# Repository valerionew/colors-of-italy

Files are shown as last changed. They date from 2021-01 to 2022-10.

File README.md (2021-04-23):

# Colors of Italy

# <a href="https://valerionew.github.io/colors-of-italy/" target="_blank">https://valerionew.github.io/colors-of-italy/</a>
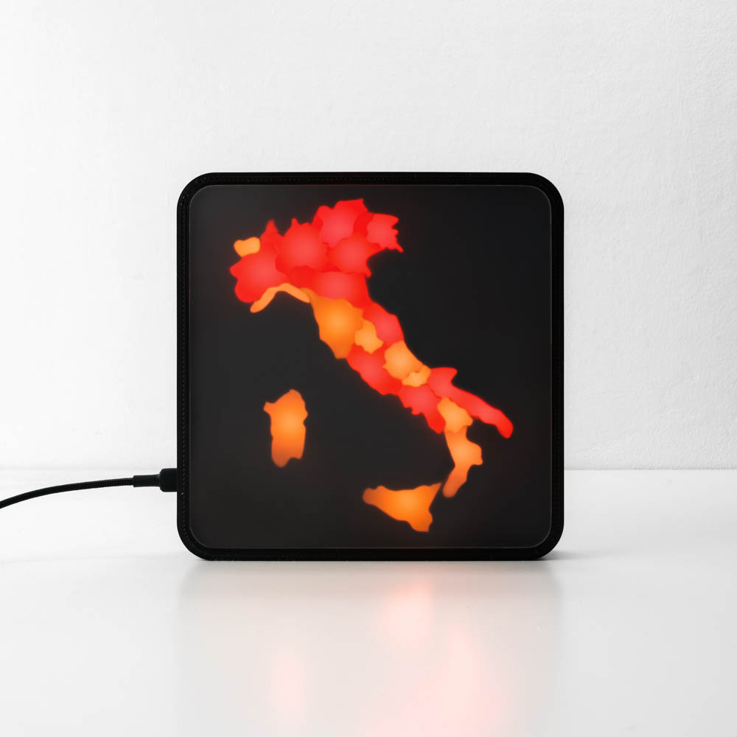
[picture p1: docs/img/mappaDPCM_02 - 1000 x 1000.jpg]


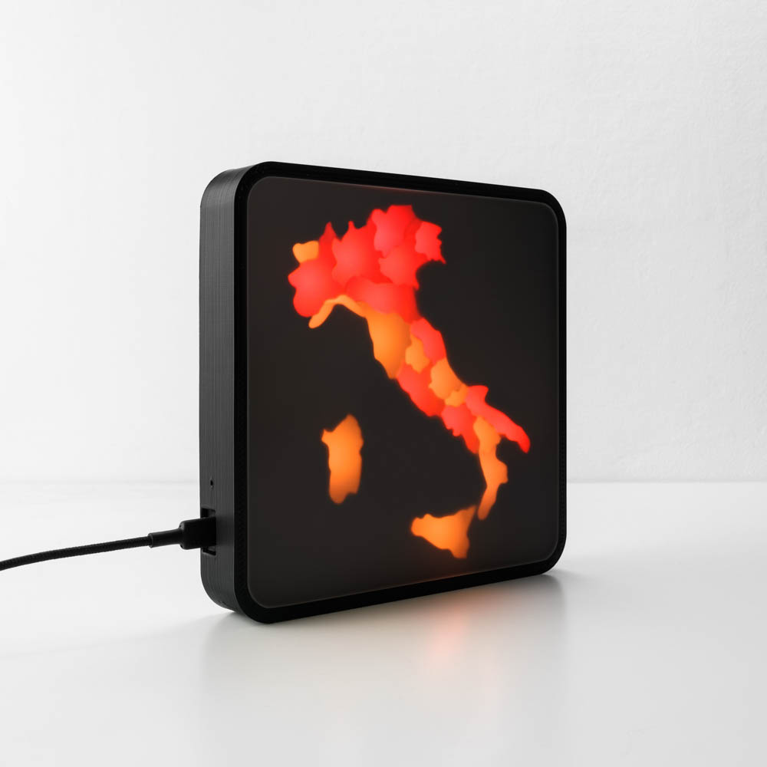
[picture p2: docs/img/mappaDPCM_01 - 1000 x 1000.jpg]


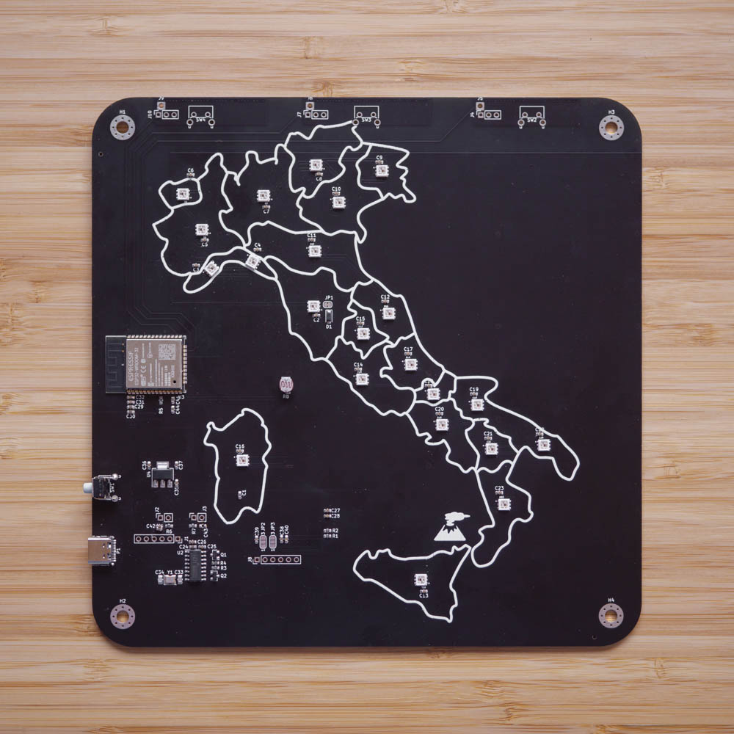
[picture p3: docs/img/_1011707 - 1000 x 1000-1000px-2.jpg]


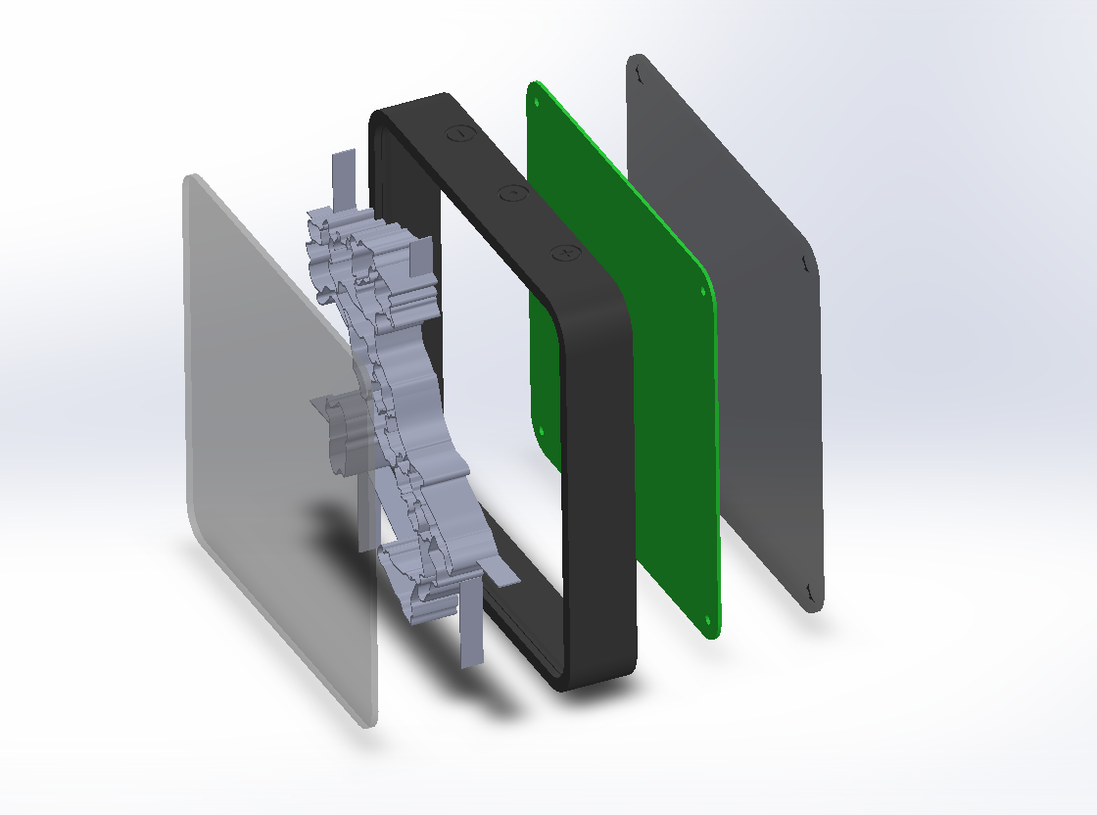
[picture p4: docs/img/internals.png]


inspired by http://www.lucadentella.it/en/2021/01/09/impariamo-insieme-mappa-dinamica-con-arduino/

Using https://github.com/wokwi/kicad-jlcpcb-bom-plugin for BOM management

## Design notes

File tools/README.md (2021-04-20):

## Colors of Italy Tools
Here are some tools for calibration and debug of the system

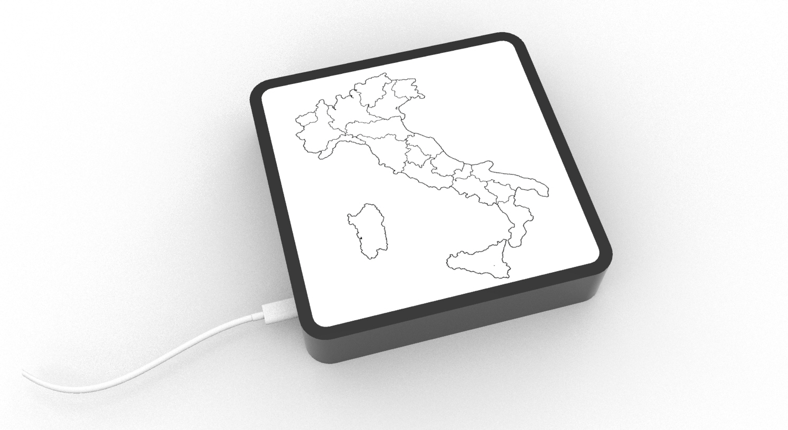
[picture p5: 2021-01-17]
proof-of-concept/proof-of-concept-v.jpg

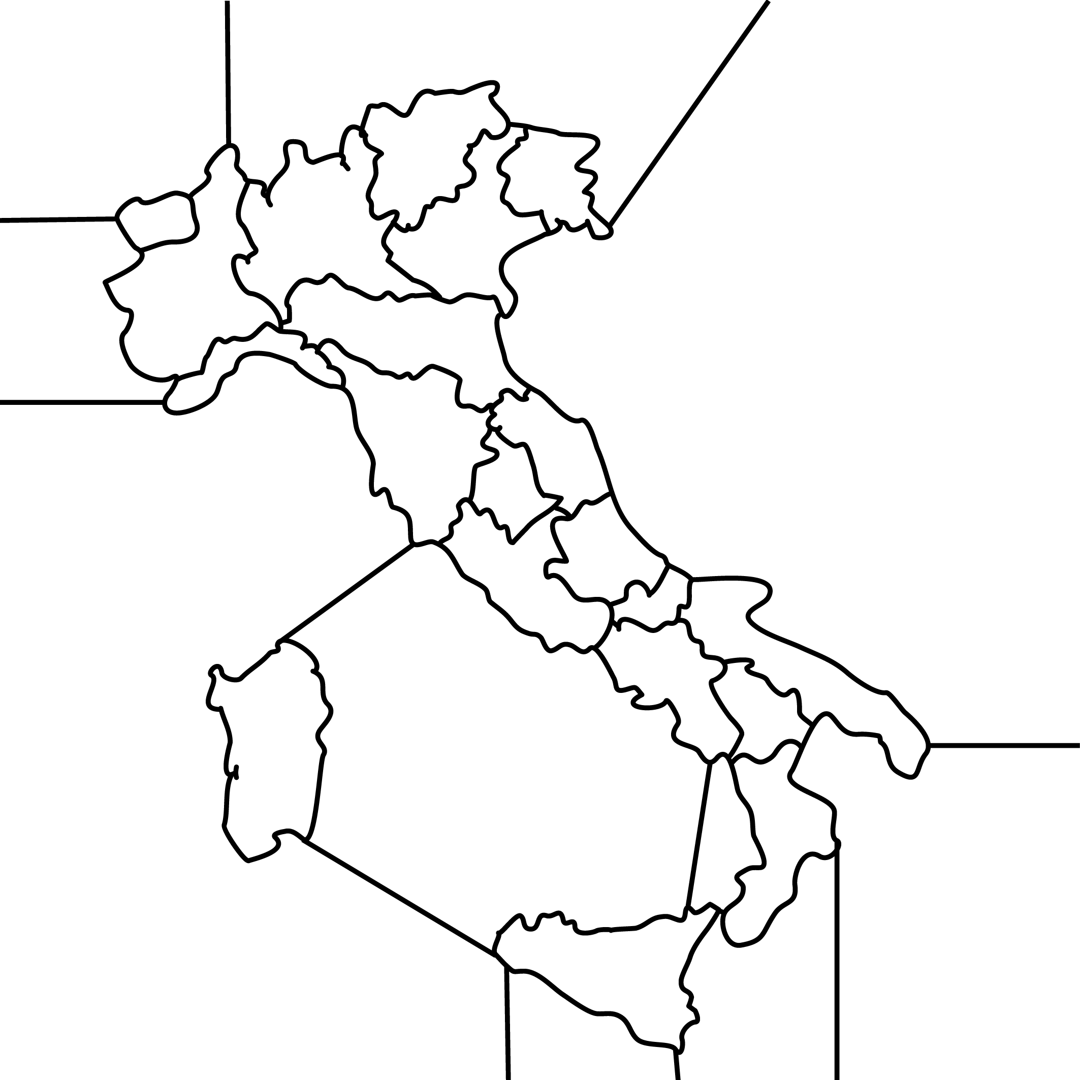
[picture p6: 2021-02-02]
hardware/confini-per-pcb-art-01.png

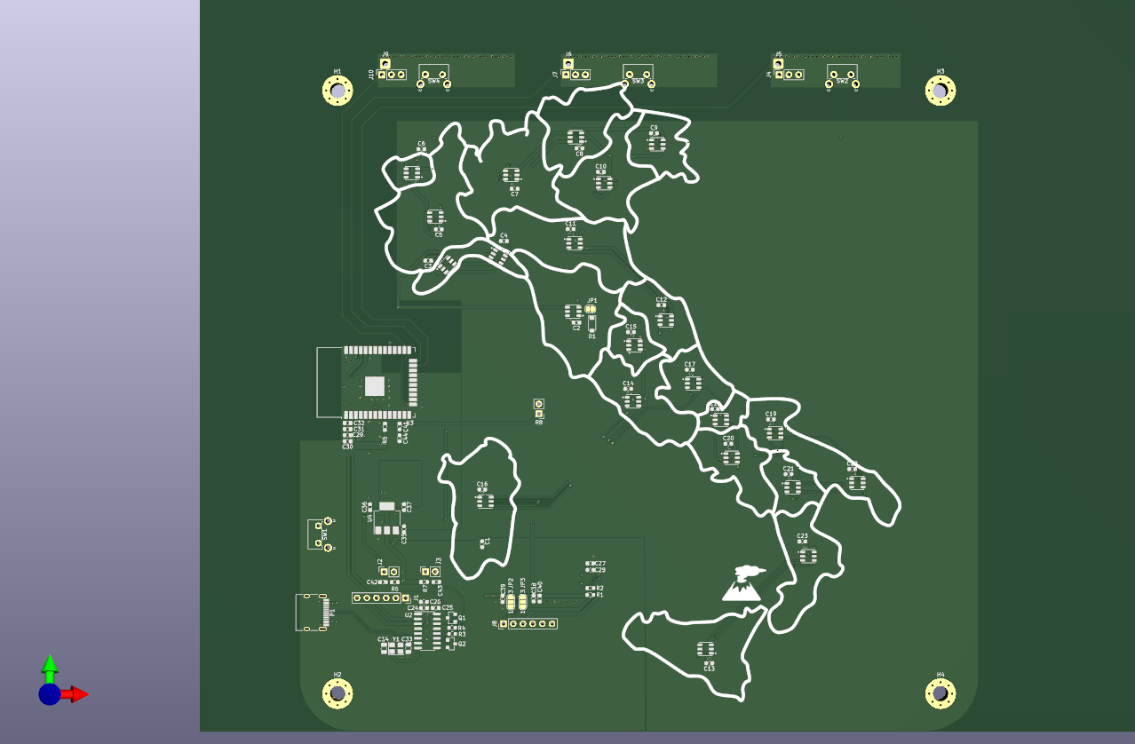
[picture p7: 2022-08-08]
hardware/Colors-of-Italy-pcb.png

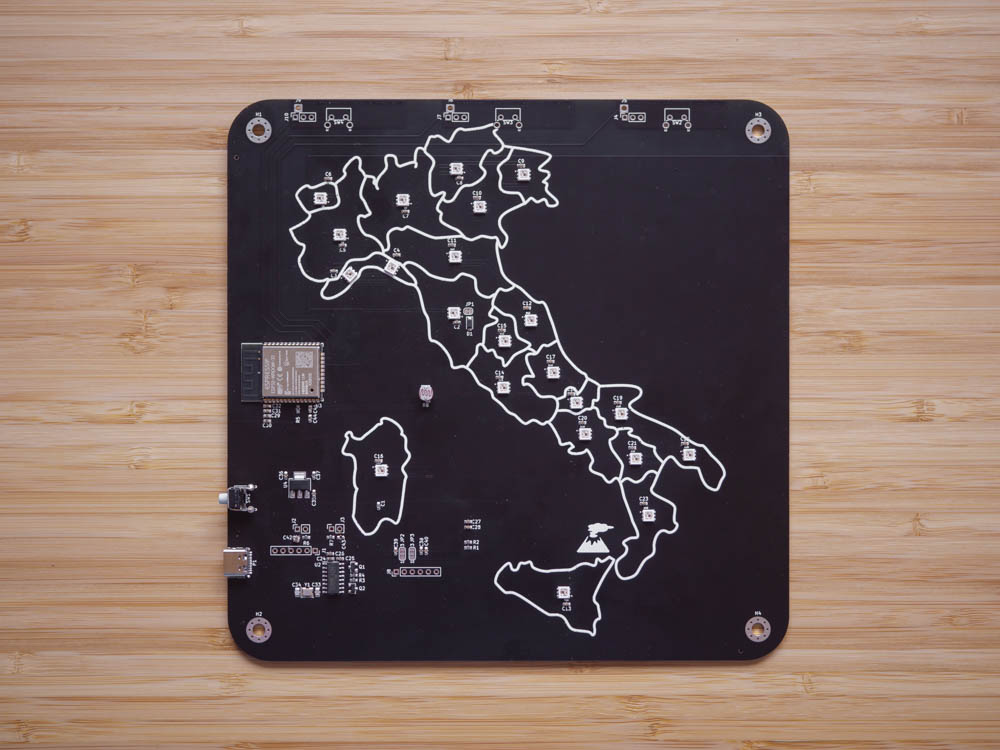
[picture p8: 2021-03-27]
docs/img/_1011707 - 1000 x 1000.jpg

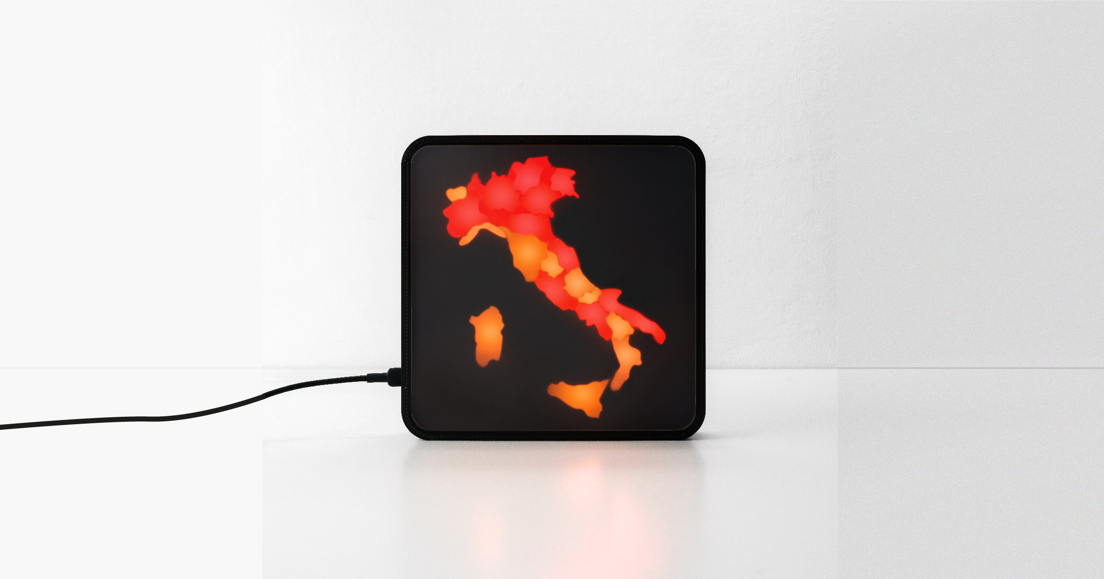
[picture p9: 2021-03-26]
docs/img/mappaDPCM_02 - thumbnail.jpg

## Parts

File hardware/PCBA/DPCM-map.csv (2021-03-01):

Comment | Designator | Footprint | LCSC Part #
10u Unpolarized capacitor | C1,C24,C27,C29,C30,C35,C37,C38,C39,C41,C43,C44 | C_0603_1608Metric | C19702
100n Unpolarized capacitor | C2,C3,C4,C5,C6,C7,C8,C9,C10,C11,C12,C13,C14,C15,C16,C17,C18,C19,C20,C21,C22,C23,C25,C26,C28,C31,C32,C36,C40,C42 | C_0603_1608Metric | C14663
18p Unpolarized capacitor, small symbol | C33,C34 | C_0805_2012Metric | C1797
1N4148W 100V 0.15A standard switching diode, DO-35 | D1 | D_SOD-123 | C81598
WS2813 RGB LED with integrated controller | D2,D3,D4,D5,D6,D7,D8,D9,D10,D11,D12,D13,D14,D15,D16,D17,D18,D19,D20,D21,D22,D23 | LED_WS2813-MINI | C189639
USB_C_Plug USB Type-C Plug connector | P1 | USB_C_Receptacle_HRO_TYPE-C-31-M-12 | C165948
2N7002 N-MOSFET transistor, gate/source/drain | Q1,Q2 | SOT-23 | C8545
10k Resistor | R1,R2,R3,R4,R5,R6,R7 | R_0603_1608Metric | C25804
CH340G USB serial converter, UART, SOIC-16 | U2 | SOIC-16_3.9x9.9mm_P1.27mm | C14267
ESP32-WROOM-32 RF Module, ESP32-D0WDQ6 SoC, Wi-Fi 802.11b/g/n, Bluetooth, BLE, 32-bit, 2.7-3.6V, onboard antenna, SMD | U3 | ESP32-WROOM-32 | C82899
AZ1117-3.3 1A 20V Fixed LDO Linear Regulator, 3.3V, SOT-89/SOT-223/TO-220/TO-252/TO-263 | U4 | SOT-223-3_TabPin2 | C6186
12MHz Four pin crystal, GND on pins 2 and 4 | Y1 | Crystal_SMD_3225-4Pin_3.2x2.5mm | C9002

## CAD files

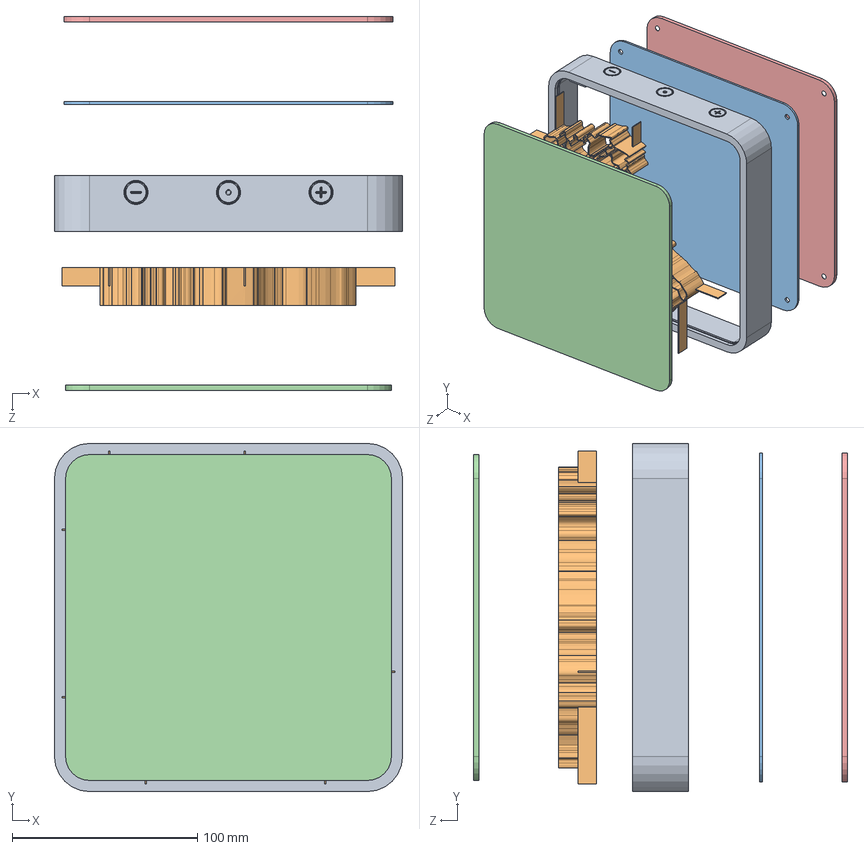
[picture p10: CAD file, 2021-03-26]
mechanical/Assembly-lite.SLDASM
188.1 x 188.1 x 202.0 mm
frame-lite
regioni^Assembly-lite
PCB^Assembly-lite
front^Assembly-lite
back^Assembly-lite

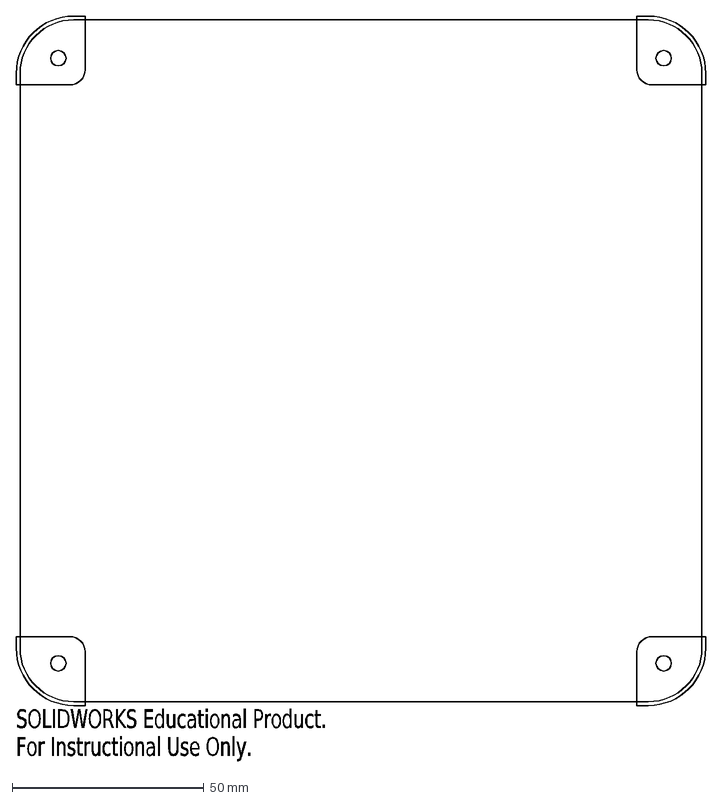
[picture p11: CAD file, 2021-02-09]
hardware/keepouts.dxf
SOLIDWORKS Educational Product.
For Instructional Use Only.

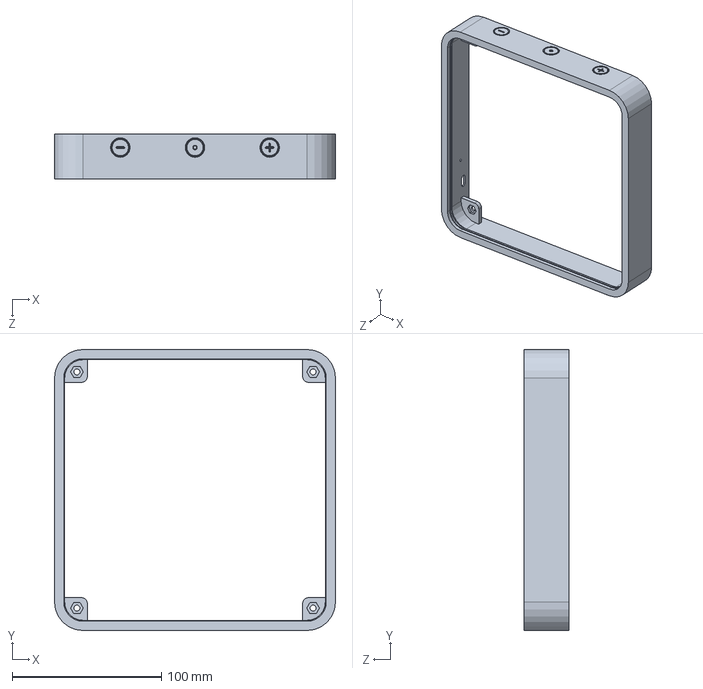
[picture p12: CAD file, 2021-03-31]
mechanical/frame-lite.SLDPRT
188.1 x 188.1 x 30.0 mm

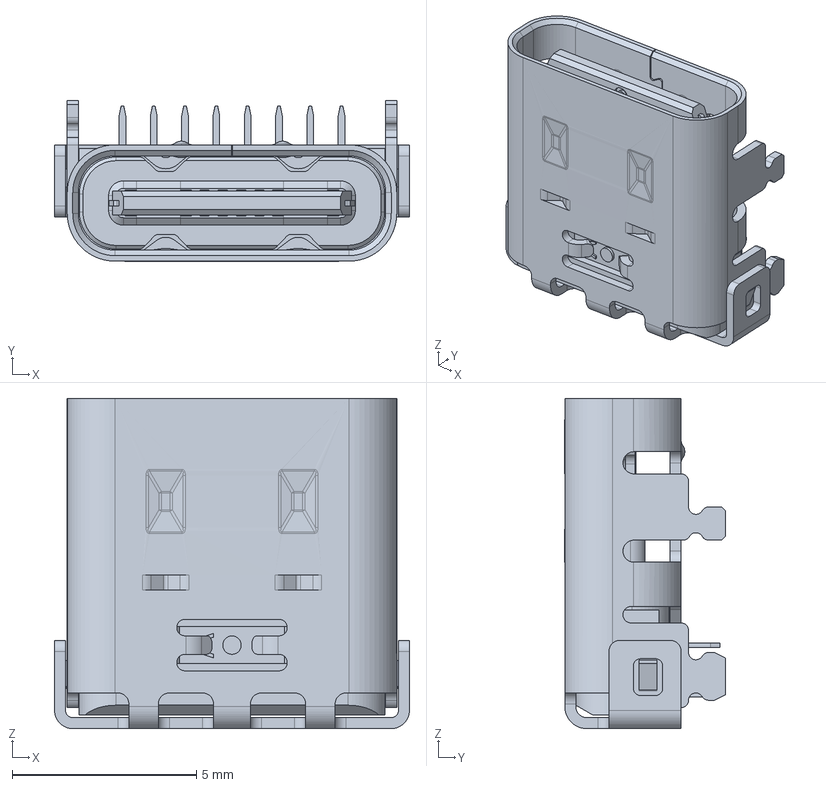
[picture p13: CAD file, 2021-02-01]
mechanical/assets/2137160001.stp
9.64 x 4.36 x 8.97 mm

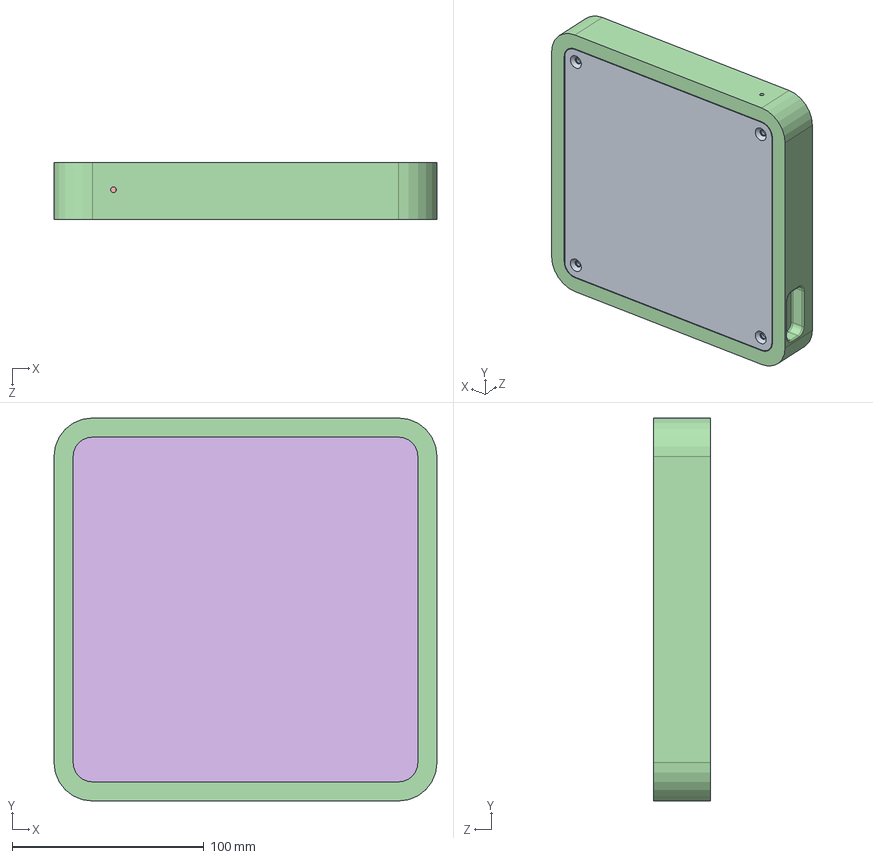
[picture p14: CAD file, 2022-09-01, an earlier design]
mechanical/old/Assembly.SLDASM
200.0 x 200.0 x 30.0 mm
PCB
Part1^Assembly
frame
regioni^Assembly

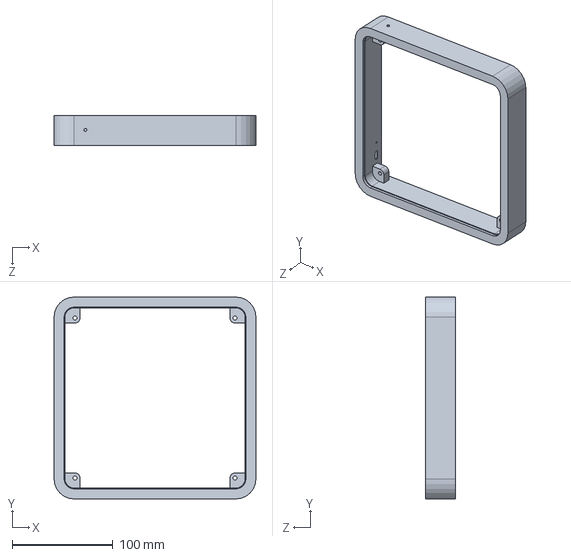
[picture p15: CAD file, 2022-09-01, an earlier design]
mechanical/old/frame.SLDPRT
200.0 x 200.0 x 30.0 mm

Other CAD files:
mechanical/assets/top-buttons.dxf
mechanical/STL/3MF/CE3_frame-lite.3mf
mechanical/STL/back.dxf
hardware/edges.dxf
mechanical/assets/italy-supports.dxf
mechanical/STL/front.dxf
mechanical/assets/italy-support.dxf
mechanical/old/Assembly-lite.SLDASM
mechanical/old/screen.SLDPRT
mechanical/old/Coperchio.SLDPRT
mechanical/old/frame-lite.SLDPRT
mechanical/old/PCB.SLDPRT
mechanical/STL/frame-lite.stl
mechanical/old/regioni.SLDPRT
proof-of-concept/proof-of-concept-v.3dm

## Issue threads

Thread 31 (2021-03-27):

Mappa vaccinati

Testato, 2021-03-27:
Come già fatto sul progetto di Luca dentella usare la mappa anche per visualizzare l'andazzo dei vaccinati.

Un paio di visualizzazioni utili:
- percentuali di vaccini iniettati rispetto ai consegnati per regione
- percentuali di vaccinati rispetto alla popolazione della regione

Closed 2022-07-30.

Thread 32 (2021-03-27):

Pdf pcb+sch

Testato, 2021-03-27:
Per chi al volo, magari su smartphone, vuole dare un'occhiata a schema elettrico e pcb, è utile inserire due .pdf aggiornati di volta in volta all'ultima release

valerionew, 2021-04-10:
Grazie per il suggerimento, fatto in 288a203!

Testato, 2022-08-06:
è stato aggiunto solo il .pdf dello schema, non anche il .pdf del pcb ?

Testato, 2022-08-08:
Closed by https://github.com/valerionew/colors-of-italy/commit/67d5a37c0be215f8fd7a4a17aa0f6b96717bcda0

Closed 2022-08-08.

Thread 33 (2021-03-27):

fetch dei dati

WAPEETY, 2021-03-27:
Salve, per essere sicuri che i dati siano sempre aggiornati non converrebbe prenderli da [https://github.com/pcm-dpc/COVID-19](https://github.com/pcm-dpc/COVID-19) ?

vi ringrazio in anticipo per la risposta.

valerionew, 2021-04-10:
Ciao e grazie per il suggerimento.
Quelli distribuiti dalla protezione civile sono dei [JSON enormi](https://raw.githubusercontent.com/pcm-dpc/COVID-19/master/aree/geojson/dpc-covid-19-ita-aree.json), non è molto conveniente scaricarli e parsarli sul dispositivo. In più avevamo già questi dati per un altro progetto di @lorossi, che fa scraping su una pagina del ministero, quindi sono comunque aggiornati

WAPEETY, 2021-04-10:
In effetti ho notato adesso, scaricarli e parsarli su un ESP sarebbe praticamente una mazzata mazzata per il microcontrollore ahahahah.
Grazie ancora, chiudo la issue

Closed 2021-04-10.

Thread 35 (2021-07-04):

Portscan bug

Testato, 2021-07-04:
lanciando un portscan verso il device, la mappa inizia a lampeggiare.
Alla fine del port scan la mappa puo' risultare a volte accesa ed a volte spenta

valerionew, 2021-07-04:
Confermato

valerionew, 2021-07-04:
Da prime prove sembra dovuto a un'interferenza tra i bottoni touch e l'uso del wifi

Testato, 2021-07-04:
Concordo, è lo stesso effetto di quando ti avvicini colle mani.
Il touch è il tallone d'Achille del progetto

valerionew, 2021-07-04:
Nella roadmap non ci doveva nemmeno essere per la v1, abbiamo deciso di inserirlo nell'hardware "per uso futuro" e abbiamo tentato un'implementazione. È sicuramente una criticità, ma non è mai stato uno dei punti chiave del progetto - tanto che per metà è disabilitato e funziona solo il tasto centrale

Testato, 2021-07-04:
io prenderei in considerazione un update per rimuovere anche il tasto centrale, tanto dà solo problemi e se si vuole spegnere si stacca il cavo

valerionew, 2021-07-04:
Io lo uso ogni sera sulla mia unità, ma effettivamente alcune mattine la trovo accesa. Se vuoi ti mando un compilato senza tasto centrale, se pensi sia più comodo

Testato, 2021-07-04:
non preoccuparti, era giusto per segnalare la issue, se impegno ci deve essere è meglio mettere mano al touch in se

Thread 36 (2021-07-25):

Splashscreen

Testato, 2021-07-25:
aggiungere una qualsiasi animazione, o anche una semplice accensione di tutti i led per 1sec, al boot.
Questo aiuta il debug nel caso in cui, causa rpobemi magari al server, la lampada rimane completamente spenta (come è in questo momento), ed anche staccando e riattaccando l'alimentazione non c'e' segno di vita, facendo erroneamente credere che magari non c'e' alimentazione, o sono rotti i led, ecc ecc

Testato, 2022-10-16:
Inserita bandiera italiana al boot

Closed 2022-10-16.

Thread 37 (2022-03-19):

[Feature Request] Wars of Italy

Testato, 2022-03-19:
Rilasciare un nuovo firmware che permetta la visualizzazione delle regioni bombardate nel caso si arrivi ad una guerra con Putin

Testato, 2022-07-30:
speriamo non serva 😅

Closed 2022-07-30.

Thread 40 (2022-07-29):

Down vaccinocovid19.live

Testato, 2022-07-29:
Risulta down vaccinocovid19.live, sia tentando di raggiungere l'indirizzo via browser sia confermato da debug seriale
Il device resta su schermata nera

```
cer*WM: [3] lastconxresult: WL_CONNECTED                                
[E][WiFiGeneric.cpp:739] hostByName(): DNS Failed for vaccinocovid19.live
[E][WiFiClientSecure.cpp:127] connect(): start_ssl_client: -1           
[E][WiFiGeneric.cpp:739] hostByName(): DNS Failed for vaccinocovid19.live
[E][WiFiClientSecure.cpp:127] connect(): start_ssl_client: -1
```

valerionew, 2022-07-30:
@lorossi

Testato, 2022-10-16:
Rimossa la necessità di un server esterno

Closed 2022-10-16.

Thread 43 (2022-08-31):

Reverse USB-C

Testato, 2022-08-31:
L'attuale modello di connettore Usb-C fa perdere la funzionalità di reverse del cavo Usb-c.
Cambiare modello in caso di nuova produzione

valerionew, 2022-08-31:
Pro USB c full:
- Funziona con tutti i cavi in tutti gli orientamenti
Contro USB c full:
- Non testato
- Considerevolmente più costoso
- Non se ne accorge praticamente nessuno, se non durante lo sviluppo

Testato, 2022-08-31:
Non testato in che senso ? Funziona al 100% il reverse sul connettore giusto.
Per il prezzo bisogna vedere, magari costa 2€ invece di 1€
il terzo punto è incontestabile :-)

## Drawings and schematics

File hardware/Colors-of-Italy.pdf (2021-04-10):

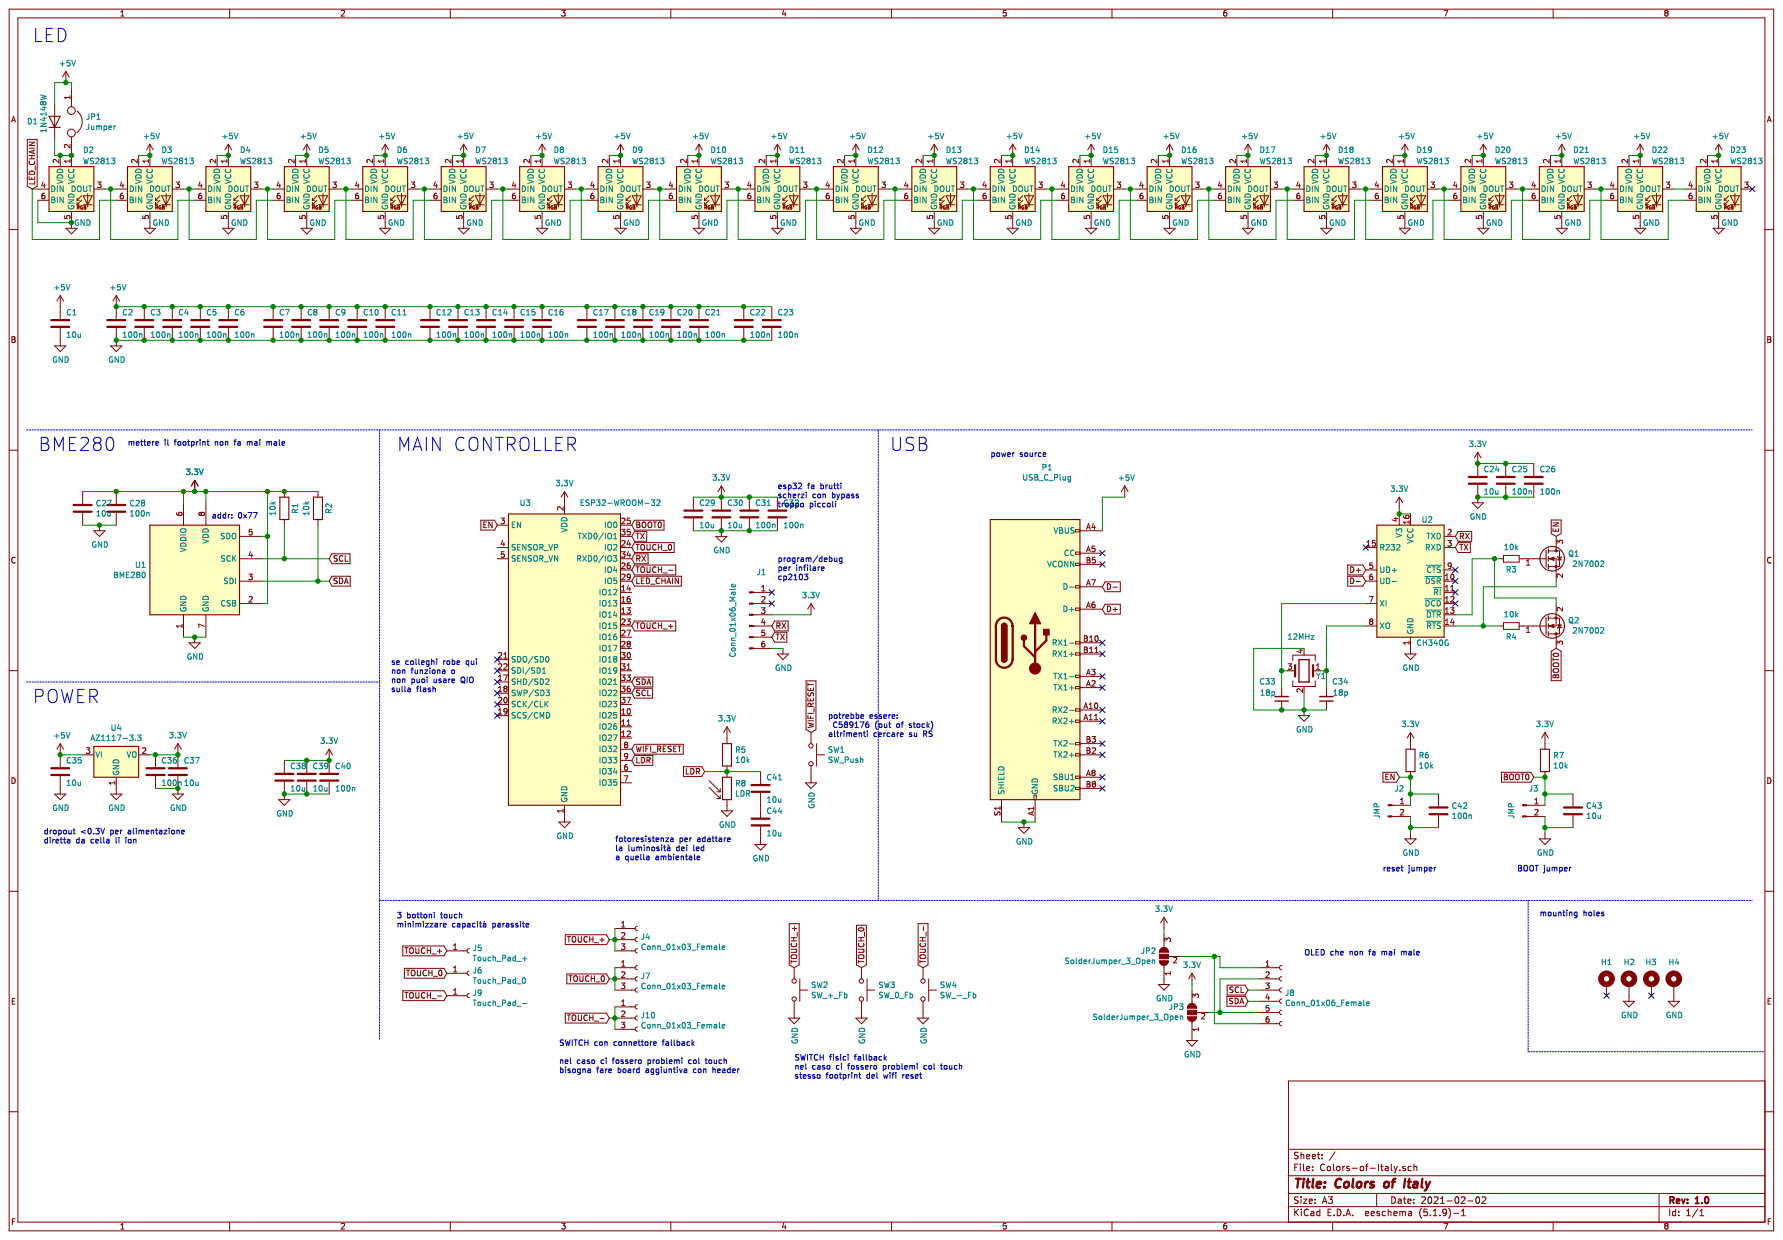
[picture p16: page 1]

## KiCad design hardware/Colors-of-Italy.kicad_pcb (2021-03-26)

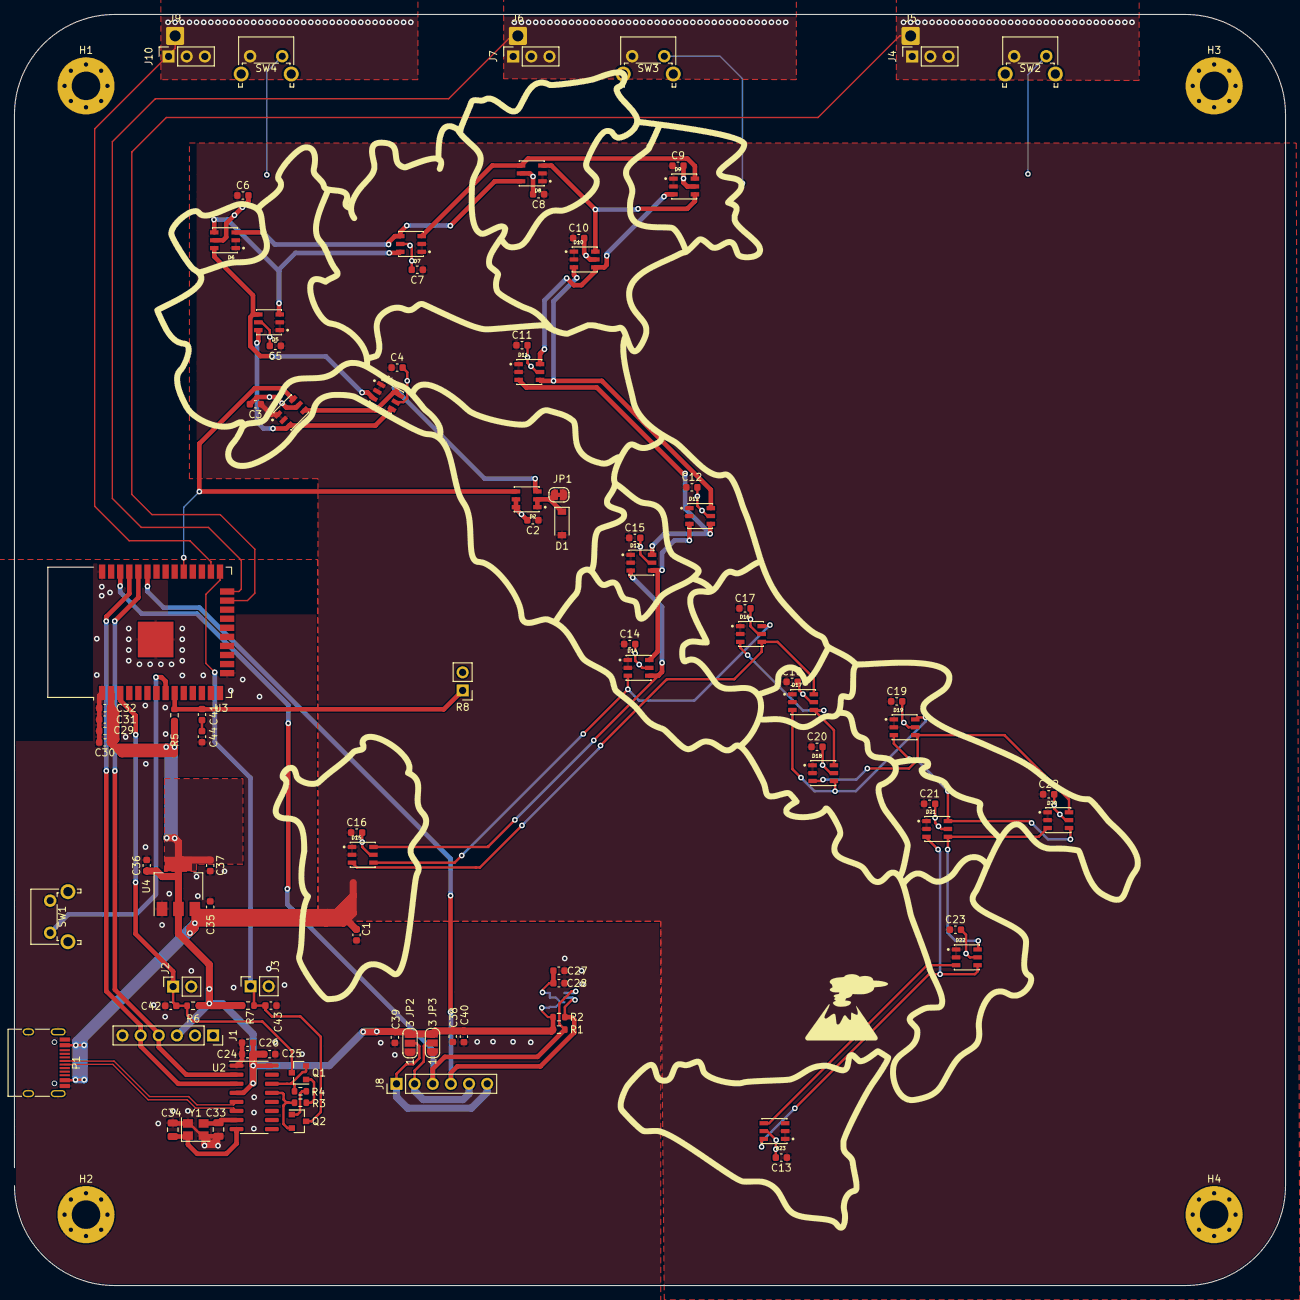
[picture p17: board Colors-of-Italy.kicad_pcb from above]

Board: 2 copper layers, 178.0 x 178.0 mm, 104 parts (1 on the bottom side), 48 nets.

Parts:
C1, C24, C27, C29, C30, C35, C37, C38, C39, C41, C43, C44: 10u; C_0603_1608Metric
C2, C3, C4, C5, C6, C7, C8, C9, C10, C11, C12, C13, C14, C15, C16, C17, C18, C19, C20, C21, C22, C23, C25, C26, C28, C31, C32, C36, C40, C42: 100n; C_0603_1608Metric
C33, C34: 18p; C_0805_2012Metric
D1: 1N4148W; D_SOD-123
D2, D3, D4, D5, D6, D7, D8, D9, D10, D11, D12, D13, D14, D15, D16, D17, D18, D19, D20, D21, D22, D23: WS2813; LED_WS2813-MINI
H1, H2, H3, H4: MountingHole_Pad; MountingHole_4mm_Pad_Via
J1: Conn_01x06_Male; PinSocket_1x06_P2.54mm_Vertical
J2, J3: JMP; PinSocket_1x02_P2.54mm_Vertical
J4, J7, J10: Conn_01x03_Female; PinSocket_1x03_P2.54mm_Vertical
J5: Touch_Pad_+; SolderWire-0.75sqmm_1x01_D1.25mm_OD2.3mm
J6: Touch_Pad_0; SolderWire-0.75sqmm_1x01_D1.25mm_OD2.3mm
J8: Conn_01x06_Female; PinHeader_1x06_P2.54mm_Vertical
J9: Touch_Pad_-; SolderWire-0.75sqmm_1x01_D1.25mm_OD2.3mm
JP1: Jumper; SolderJumper-2_P1.3mm_Bridged_RoundedPad1.0x1.5mm
JP2, JP3: SolderJumper_3_Open; SolderJumper-3_P1.3mm_Open_RoundedPad1.0x1.5mm_NumberLabels
P1: USB_C_Plug; USB_C_Receptacle_HRO_TYPE-C-31-M-12
Q1, Q2: 2N7002; SOT-23
R1, R2, R3, R4, R5, R6, R7: 10k; R_0603_1608Metric
R8: LDR; PinHeader_1x02_P2.54mm_Vertical
SW1: SW_Push; SW_Tactile_SPST_Angled_PTS645Vx58-2LFS
SW2: SW_+_Fb; SW_Tactile_SPST_Angled_PTS645Vx58-2LFS
SW3: SW_0_Fb; SW_Tactile_SPST_Angled_PTS645Vx58-2LFS
SW4: SW_-_Fb; SW_Tactile_SPST_Angled_PTS645Vx58-2LFS
U1: BME280; Bosch_LGA-8_2.5x2.5mm_P0.65mm_ClockwisePinNumbering
U2: CH340G; SOIC-16_3.9x9.9mm_P1.27mm
U3: ESP32-WROOM-32
U4: AZ1117-3.3; SOT-223-3_TabPin2
Y1: 12MHz; Crystal_SMD_3225-4Pin_3.2x2.5mm

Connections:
+3V3: C24.1, C25.1, C26.1, C27.1, C28.1, C29.1, C30.1, C31.1, C32.1, C36.1, C37.1, C38.1, C39.1, C40.1, J1.3, JP2.3, JP3.3, R1.2, R2.2, R5.1, R6.1, R7.1, U1.2, U1.5, U1.6, U1.8, U2.4, U2.16, U3.2, U4.2
+5V: C1.1, C2.1, C3.1, C4.1, C5.1, C6.1, C7.1, C8.1, C9.1, C10.1, C11.1, C12.1, C13.1, C14.1, C15.1, C16.1, C17.1, C18.1, C19.1, C20.1, C21.1, C22.1, C23.1, C35.1, D1.2, D3.1, D3.2, D4.1, D4.2, D5.1, D5.2, D6.1, D6.2, D7.1, D7.2, D8.1, D8.2, D9.1, D9.2, D10.1, D10.2, D11.1, D11.2, D12.1, D12.2, D13.1, D13.2, D14.1, D14.2, D15.1, D15.2, D16.1, D16.2, D17.1, D17.2, D18.1, D18.2, D19.1, D19.2, D20.1, D20.2, D21.1, D21.2, D22.1, D22.2, D23.1, D23.2, JP1.1, P1.A4, P1.A9, P1.B4, P1.B9, U4.3
BOOT0: C43.1, J3.1, Q2.3, R7.2, U3.25
D+: P1.A6, U2.5
D-: P1.A7, U2.6
EN: C42.1, J2.1, Q1.3, R6.2, U3.3
GND: C1.2, C2.2, C3.2, C4.2, C5.2, C6.2, C7.2, C8.2, C9.2, C10.2, C11.2, C12.2, C13.2, C14.2, C15.2, C16.2, C17.2, C18.2, C19.2, C20.2, C21.2, C22.2, C23.2, C24.2, C25.2, C26.2, C27.2, C28.2, C29.2, C30.2, C31.2, C32.2, C33.1, C34.1, C35.2, C36.2, C37.2, C38.2, C39.2, C40.2, C42.2, C43.2, C44.2, D2.5, D2.6, D3.5, D4.5, D5.5, D6.5, D7.5, D8.5, D9.5, D10.5, D11.5, D12.5, D13.5, D14.5, D15.5, D16.5, D17.5, D18.5, D19.5, D20.5, D21.5, D22.5, D23.5, H2.1, H4.1, J1.6, J2.2, J3.2, JP2.1, JP3.1, P1.A1, P1.A12, P1.B1, P1.B12, P1.S1, R8.2, SW1.2, SW2.2, SW3.2, SW4.2, U1.1, U1.7, U2.1, U3.1, U3.15, U3.38, U3.39, U4.1, Y1.2, Y1.4
LDR: C41.1, R5.2, R8.1, U3.9
LED_CHAIN: D2.4, D3.6, U3.29
unnamed: C33.2, U2.7, Y1.3
unnamed: C34.2, U2.8, Y1.1
unnamed: C41.2, C44.1
unnamed: D1.1, D2.1, D2.2, JP1.2
unnamed: D2.3, D3.4, D4.6
unnamed: D3.3, D4.4, D5.6
unnamed: D4.3, D5.4, D6.6
unnamed: D5.3, D6.4, D7.6
unnamed: D6.3, D7.4, D8.6
unnamed: D7.3, D8.4, D9.6
unnamed: D10.3, D11.4, D12.6
unnamed: D9.3, D10.4, D11.6
unnamed: D8.3, D9.4, D10.6
unnamed: D11.3, D12.4, D13.6
unnamed: D12.3, D13.4, D14.6
unnamed: D13.3, D14.4, D15.6
unnamed: D14.3, D15.4, D16.6
unnamed: D15.3, D16.4, D17.6
unnamed: D16.3, D17.4, D18.6
unnamed: D17.3, D18.4, D19.6
unnamed: D18.3, D19.4, D20.6
unnamed: D19.3, D20.4, D21.6
unnamed: D20.3, D21.4, D22.6
unnamed: D21.3, D22.4, D23.6
unnamed: D22.3, D23.4
unnamed: J8.1, J8.6, JP2.2
unnamed: J8.2, J8.5, JP3.2
unnamed: Q1.1, R3.2
unnamed: Q1.2, R4.1, U2.14
unnamed: Q2.1, R4.2
unnamed: Q2.2, R3.1, U2.13
RX: J1.4, U2.2, U3.34
SCL: J8.3, R1.1, U1.4, U3.36
SDA: J8.4, R2.1, U1.3, U3.33
TOUCH_0: J6.1, J7.1, J7.2, J7.3, SW3.1, U3.24
TOUCH_+: J4.1, J4.2, J4.3, J5.1, SW2.1, U3.23
TOUCH_-: J9.1, J10.1, J10.2, J10.3, SW4.1, U3.26
TX: J1.5, U2.3, U3.35
WIFI_RESET: SW1.1, U3.8

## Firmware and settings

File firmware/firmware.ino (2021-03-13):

#include <WiFi.h>
#include <WebServer.h>
#include <WiFiManager.h> // https://github.com/tzapu/WiFiManager -use development branch to get it working on esp32
#include <ArduinoJson.h> // https://github.com/bblanchon/ArduinoJson
#include <FastLED.h>     // https://github.com/FastLED/FastLED
#include <HTTPClient.h>  // built in library
#include <map>           // built in library
#include <array>         // built in library

#define DEBUG

#define LED_NUMBER 22         // change this with the actual number of leds
#define MAX_LEDS_PER_REGION 2 // change this with the maximum number of led in each region
#define WIFI_TIMEOUT 500
#define WIFI_SSID_NAME "DCPM-map"
#define UPDATE_INTERVAL 10000
#define TERRITORIES_REQUEST_URL "https://vaccinocovid19.live/get/colore_territori_slim"
#define COLORS_REQUEST_URL "https://vaccinocovid19.live/get/colore_territori_rgb"
#define WIFI_RESET_BUTTON 32
#define WIFI_RESET_TIMEOUT 5000
#define WIFI_MAX_TIME 600000
#define LED_PIN 5           // pin connected to WS2812b data cable
#define LIGHT_SENSOR_PIN 33 // must be and ADC PIN, cannot use ADC2
#define NO_LED 255

#define TOUCH_PLUS_PIN T3  // GPIO 4
#define TOUCH_RESET_PIN T2 // GPIO 2
#define TOUCH_MINUS_PIN T0 // GPIO 15

WiFiManager wifiManager;
WiFiClient client;
CRGB leds[LED_NUMBER];

unsigned long last_update;
unsigned long last_pressed;

boolean wifi_connected;

// color mapping
// e.g. red -> color 0 -> 0xdd222a (red)
// initialization
std::map<String, unsigned long> color_map;

// territory mapping
// ISTAT CODE -> led position translation
// e.g. code 01 -> addresses of led_map["01"]
// source https://www.agenziaentrate.gov.it/portale/Strumenti/Codici+attivita+e+tributo/F24+Codici+tributo+per+i+versamenti/Tabelle+dei+codici+tributo+e+altri+codici+per+il+mo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
std::map<String, std::array<byte, MAX_LEDS_PER_REGION>>
    led_map = {
        {"01", {14, NO_LED}}, // ABRUZZO
        {"02", {19, NO_LED}}, // BASILICATA
        {"03", {NO_LED}},     // BOLZANO
        {"04", {20, NO_LED}}, // CALABRIA
        {"05", {16, NO_LED}}, // CAMPANIA
        {"06", {9, NO_LED}},  // EMILIA ROMAGNA
        {"07", {7, NO_LED}},  // FRIULI VENEZIA GIULIA
        {"08", {12, NO_LED}}, // LAZIO
        {"09", {1, 2}},       // LIGURIA
        {"10", {5, NO_LED}},  // LOMBARDIA
        {"11", {10, NO_LED}}, // MARCHE
        {"12", {15, NO_LED}}, // MOLISE
        {"13", {3, NO_LED}},  // PIEMONTE
        {"14", {17, 18}},     // PUGLIA
        {"15", {13, NO_LED}}, // SARDEGNA
        {"16", {21, NO_LED}}, // SICILIA
        {"17", {0, NO_LED}},  // TOSCANA
        {"18", {6, NO_LED}},  // TRENTO
        {"19", {11, NO_LED}}, // UMBRIA
        {"20", {4, NO_LED}},  // VALLE D'AOSTA
        {"21", {8, NO_LED}}   // VENETO
};

// this function gets called when the parameters are set
void wifiParametersSet()
{
#ifdef DEBUG
  Serial.println("Wifi parameters set. Resetting ESP32.");
#endif
  ESP.restart();
}

void setup()
{

#ifdef DEBUG
  Serial.begin(115200);
#endif

  // PINs initialization
  pinMode(WIFI_RESET_BUTTON, INPUT_PULLUP);
  pinMode(LIGHT_SENSOR_PIN, INPUT);

  // variables initialization
  last_update = 0;
  last_pressed = 0;

#ifdef DEBUG
  Serial.println(WiFi.status());
  //wifiManager.resetSettings();
#endif

  // set up WS2812b - in realtà sono 2813 mini
  FastLED.addLeds<WS2812, LED_PIN, GRB>(leds, LED_NUMBER);

  // setup non blocking loop

  wifiManager.setHostname(WIFI_SSID_NAME);
  wifiManager.setConfigPortalBlocking(false);
  wifiManager.setSaveConfigCallback(wifiParametersSet);

  unsigned long wifiStarted = millis();
  if (!wifiManager.autoConnect(WIFI_SSID_NAME))
  {
    while (!wifi_connected)
    {
      // ConfigPortal is now running
      wifiManager.process();

      // handle led animation
      EVERY_N_MILLISECONDS(20)
      {
        pacifica_loop();
        FastLED.show();
      }

      // handle wifi reset button
      if (digitalRead(WIFI_RESET_BUTTON) == LOW)
      {
        if (last_pressed == 0)
        {
          last_pressed = millis();
        }
        else if (millis() - last_pressed > WIFI_RESET_TIMEOUT)
        {
          // delete wifi credentials and reset esp
          wifiManager.resetSettings();
          ESP.restart();
        }
      }
      else if (digitalRead(WIFI_RESET_BUTTON) == HIGH && last_pressed != 0)
      {
        // reset last pressed
        last_pressed = 0;
      }

      // handle wifi timeout
      if (millis() - wifiStarted > WIFI_MAX_TIME)
      {
        // it's taking too long to connect in
        // reset everything
        ESP.restart();
      }
    }
  }
}

void loop()
{
  // check if it's time to update
  if (last_update == 0 || millis() - last_update > UPDATE_INTERVAL)
  {
    // check if client is still connected
    // if not, set the esp in wifimanager again
    if (!client.connected())
    {
      if (!wifiManager.autoConnect(WIFI_SSID_NAME))
      {
        // blocking loop waiting for connection
        // this code gets called after timeout is hit
        ESP.restart();
      }
    }
    last_update = millis();

    HTTPClient http;
    int httpResponseCode;

    // get rgb colors
    http.begin(COLORS_REQUEST_URL);
    httpResponseCode = http.GET();
    if (httpResponseCode > 0)
    {
      StaticJsonDocument<128> doc;
      // buffer size calculated here: https://arduinojson.org/v6/assistant/
      String json_data = http.getString();
      // parse JSON data
      DeserializationError err = deserializeJson(doc, json_data);

      if (!err)
      {
        // no error in parsing
        JsonObject obj = doc.as<JsonObject>();
        for (JsonPair p : obj)
        {
          // iterate through each key and value
          // load color code
          String color_code = p.key().c_str();
          // load color value
          unsigned long color_hex = p.value().as<unsigned long>();
          // assing to map
          color_map[color_code] = color_hex;
#ifdef DEBUG
          Serial.print("color code ");
          Serial.print(color_code);
          Serial.print(" color hex ");
          Serial.println(color_hex);
#endif
        }
      }
    }

    // get territories color
    http.begin(TERRITORIES_REQUEST_URL);
    httpResponseCode = http.GET();
    if (httpResponseCode > 0)
    {
      StaticJsonDocument<512> doc;
      // buffer size calculated here: https://arduinojson.org/v6/assistant/
      String json_data = http.getString();
      // parse JSON data
      DeserializationError err = deserializeJson(doc, json_data);

      if (!err)
      {
        // no error in parsing
        JsonObject obj = doc.as<JsonObject>();
        for (JsonPair p : obj)
        {
          // iterate through each key and value
          // load color code
          String color_code = p.value().as<String>();
          // translate it to actual hex color
          unsigned long color = color_map.find(color_code)->second;
          // load the list of addresses from the map
          std::array<byte, MAX_LEDS_PER_REGION> addresses = led_map.find(p.key().c_str())->second;
          for (const auto &address : addresses)
          {
            // color the corrisponding led
            if (address != NO_LED)
            {
              // the address must be different from the array filler
              leds[address] = color;
            }
          }

#ifdef DEBUG
          Serial.print("key ");
          Serial.print(p.key().c_str());
          Serial.print(" value ");
          Serial.print(p.value().as<byte>());
          Serial.print(" led addresses ");
          for (const auto &address : addresses)
          {
            Serial.print(address);
            Serial.print(" ");
          }
          Serial.print("color code ");
          Serial.print(color_code);
          Serial.print(" color hex ");
          Serial.println(color);
#endif
        }
      }

      // free the memory
      doc.clear();
    }
    http.end();
  }
  // read light level from sensor
  unsigned int light = analogRead(LIGHT_SENSOR_PIN);
  // 500 should be the max value
  // this will need some tweaking
  if (light > 500)
    light = 500;
  // calculate the actual brightness compared to the sensor output
  byte brightness = map(light, 500, 0, 255, 20);
  // set the leds brightness
  FastLED.setBrightness(brightness);

  //      #ifdef DEBUG
  //        Serial.print("ambient light ");
  //        Serial.print(light);
  //        Serial.print(" led brightness ");
  //        Serial.println(brightness);
  //      #endif

  if (digitalRead(WIFI_RESET_BUTTON) == LOW)
  {
    if (last_pressed == 0)
    {
      last_pressed = millis();
    }
    else if (millis() - last_pressed > WIFI_RESET_TIMEOUT)
    {
      // delete wifi credentials and reset esp
      wifiManager.resetSettings();
      ESP.restart();
    }
  }
  else if (digitalRead(WIFI_RESET_BUTTON) == HIGH && last_pressed != 0)
  {
    // reset last pressed
    last_pressed = 0;
  }

  FastLED.show();
  delay(10);
}

//
//  "Pacifica"
//  Gentle, blue-green ocean waves.
//  December 2019, Mark Kriegsman and Mary Corey March.
//  For Dan.
//
CRGBPalette16 pacifica_palette_1 =
    {0x000507, 0x000409, 0x00030B, 0x00030D, 0x000210, 0x000212, 0x000114, 0x000117,
     0x000019, 0x00001C, 0x000026, 0x000031, 0x00003B, 0x000046, 0x14554B, 0x28AA50};
CRGBPalette16 pacifica_palette_2 =
    {0x000507, 0x000409, 0x00030B, 0x00030D, 0x000210, 0x000212, 0x000114, 0x000117,
     0x000019, 0x00001C, 0x000026, 0x000031, 0x00003B, 0x000046, 0x0C5F52, 0x19BE5F};
CRGBPalette16 pacifica_palette_3 =
    {0x000208, 0x00030E, 0x000514, 0x00061A, 0x000820, 0x000927, 0x000B2D, 0x000C33,
     0x000E39, 0x001040, 0x001450, 0x001860, 0x001C70, 0x002080, 0x1040BF, 0x2060FF};

void pacifica_loop()
{
  // Increment the four "color index start" counters, one for each wave layer.
  // Each is incremented at a different speed, and the speeds vary over time.
  static uint16_t sCIStart1, sCIStart2, sCIStart3, sCIStart4;
  static uint32_t sLastms = 0;
  uint32_t ms = GET_MILLIS();
  uint32_t deltams = ms - sLastms;
  sLastms = ms;
  uint16_t speedfactor1 = beatsin16(3, 179, 269);
  uint16_t speedfactor2 = beatsin16(4, 179, 269);
  uint32_t deltams1 = (deltams * speedfactor1) / 256;
  uint32_t deltams2 = (deltams * speedfactor2) / 256;
  uint32_t deltams21 = (deltams1 + deltams2) / 2;
  sCIStart1 += (deltams1 * beatsin88(1011, 10, 13));
  sCIStart2 -= (deltams21 * beatsin88(777, 8, 11));
  sCIStart3 -= (deltams1 * beatsin88(501, 5, 7));
  sCIStart4 -= (deltams2 * beatsin88(257, 4, 6));

  // Clear out the LED array to a dim background blue-green
  fill_solid(leds, LED_NUMBER, CRGB(2, 6, 10));

  // Render each of four layers, with different scales and speeds, that vary over time
  pacifica_one_layer(pacifica_palette_1, sCIStart1, beatsin16(3, 11 * 256, 14 * 256), beatsin8(10, 70, 130), 0 - beat16(301));
  pacifica_one_layer(pacifica_palette_2, sCIStart2, beatsin16(4, 6 * 256, 9 * 256), beatsin8(17, 40, 80), beat16(401));
  pacifica_one_layer(pacifica_palette_3, sCIStart3, 6 * 256, beatsin8(9, 10, 38), 0 - beat16(503));
  pacifica_one_layer(pacifica_palette_3, sCIStart4, 5 * 256, beatsin8(8, 10, 28), beat16(601));

  // Add brighter 'whitecaps' where the waves lines up more
  pacifica_add_whitecaps();

  // Deepen the blues and greens a bit
  pacifica_deepen_colors();
}

// Add one layer of waves into the led array
void pacifica_one_layer(CRGBPalette16 &p, uint16_t cistart, uint16_t wavescale, uint8_t bri, uint16_t ioff)
{
  uint16_t ci = cistart;
  uint16_t waveangle = ioff;
  uint16_t wavescale_half = (wavescale / 2) + 20;
  for (uint16_t i = 0; i < LED_NUMBER; i++)
  {
    waveangle += 250;
    uint16_t s16 = sin16(waveangle) + 32768;
    uint16_t cs = scale16(s16, wavescale_half) + wavescale_half;
    ci += cs;
    uint16_t sindex16 = sin16(ci) + 32768;
    uint8_t sindex8 = scale16(sindex16, 240);
    CRGB c = ColorFromPalette(p, sindex8, bri, LINEARBLEND);
    leds[i] += c;
  }
}

// Add extra 'white' to areas where the four layers of light have lined up brightly
void pacifica_add_whitecaps()
{
  uint8_t basethreshold = beatsin8(9, 55, 65);
  uint8_t wave = beat8(7);

  for (uint16_t i = 0; i < LED_NUMBER; i++)
  {
    uint8_t threshold = scale8(sin8(wave), 20) + basethreshold;
    wave += 7;
    uint8_t l = leds[i].getAverageLight();
    if (l > threshold)
    {
      uint8_t overage = l - threshold;
      uint8_t overage2 = qadd8(overage, overage);
      leds[i] += CRGB(overage, overage2, qadd8(overage2, overage2));
    }
  }
}

// Deepen the blues and greens
void pacifica_deepen_colors()
{
  for (uint16_t i = 0; i < LED_NUMBER; i++)
  {
    leds[i].blue = scale8(leds[i].blue, 145);
    leds[i].green = scale8(leds[i].green, 200);
    leds[i] |= CRGB(2, 5, 7);
  }
}

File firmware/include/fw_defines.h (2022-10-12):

#ifndef FW_DEFINES_H
#define FW_DEFINES_H

//Colori ufficiali Bandiera Italiana
const CRGB VERDE {0x008c45};    //Verde: pantone 17-6153
const CRGB BIANCO {0xf4f5f0};   //Bianco: pantone 11-0601
const CRGB ROSSO {0xcd212a};    //Rosso: pantone 18-1662

// Color for MAP init
const CRGB NERO {0x0};

// led related
#define LED_NUMBER 22              // change this with the actual number of leds
#define MAX_LEDS_PER_REGION 2      // change this with the maximum number of led in each region
#define BRIGHTNESS_BLEND_CUTOFF 80 // led minimum brightness (brightness cutoff for led color blending) 0-255
#define MAX_BLEND 100              // max color blending (0-255)
#define MIN_GLOBAL_BRIGHTENSS 20   // global minimum brightness (0-255)
#define LED_PIN 5                  // pin connected to WS2812b data cable
#define NO_LED 255                 // map filler

// wifi related
#define WIFI_SSID_NAME "Colors-of-Italy" // SSID of the wifi portal
#define WIFI_RESET_BUTTON 32             // wifi reset button
#define WIFI_MAX_TIME 6e5                // timeout before the wifi portal (and the whole ESP) gets reset 6e5ms -> 10min
#define WIFI_MAX_UNCONNECTED 1.8e6       // how much time the ESP can go without being connected to the wifi 1.8e6ms -> 30 min
#define WIFI_RESET_TIMEOUT 5e3           // timeout for the WiFi AP reset button 5000ms -> 5s

// routines related
//#define UPDATE_INTERVAL 10000
#define UPDATE_INTERVAL 300e3 // 300s -> 5 min
#define REFRESH_INTERVAL 50   // 50ms -> 20fps

// URLS
#define COLORS_REQUEST_URL "https://raw.githubusercontent.com/pcm-dpc/COVID-19/master/dati-json/dpc-covid19-ita-regioni-latest.json"

// Italian regions inhabitants - http://dati.istat.it/Index.aspx?DataSetCode=DCIS_POPRES1
#define INHABITANTS_REGIONS 4252279, 123337, 9965046, 1077932, 4854633, 1197295, 1507438, 4431816, 3676285, 859572, 1489789, 5715190, 1273660, 290769, 5590681, 3912166, 539999, 1844586, 4801468, 1579181 

// light sensor related
#define LIGHT_SENSOR_PIN 33 // must be and ADC PIN, cannot use ADC2
#define MAX_BRIGHTNESS 2000 // sensor max brightness read (min is 0)

// touch related
#define TOUCH_PLUS_PIN T3       // GPIO 15
#define TOUCH_RESET_PIN T2      // GPIO 2
#define TOUCH_MINUS_PIN T0      // GPIO 4
#define BRIGHTNESS_INCREMENT 1 // bright increment for plus/minus buttons

#endif

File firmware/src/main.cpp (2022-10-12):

#include <Arduino.h>     // built in library
#include <WiFi.h>        // built in library
#include <WebServer.h>   // built in library
#include <HTTPClient.h>  // built in library
#include <numeric>       // built in library
#include <array>         // built in library
#include <WiFiManager.h> // https://github.com/tzapu/WiFiManager
#include <ArduinoJson.h> // https://github.com/bblanchon/ArduinoJson
#include <FastLED.h>     // https://github.com/FastLED/FastLED
#include "fw_defines.h"
#include "CircularBuffer.h"
#include "Regioni.h"
#include "pacifica.h"
#include "LPF.h"
#include "Button.h"

#define DEBUG

WiFiManager wifiManager;
WiFiClient client;

uint8_t brightness_scale{30};
unsigned long last_connected{0};
unsigned long last_pressed{0};

bool showing{true};

LPF brightness_filter{0.05};

Button touch_minus(TOUCH_MINUS_PIN);
Button touch_reset(TOUCH_RESET_PIN);
Button touch_plus (TOUCH_PLUS_PIN);

// force a value into and interval
float force(float value, float min, float max)
{
  if (value > max)
    value = max;
  else if (value < min)
    value = min;

  return value;
}

// rescale a value to new interval
float rescale(float value, float old_min, float old_max, float new_min, float new_max)
{
  // swap the interval if the scale is inverted
  if (old_min > old_max)
  {
    float temp = old_min;
    old_min = old_max;
    old_max = temp;
  }

  // check if the value is in range
  if (value > old_max)
    value = old_max;
  else if (value < old_min)
    value = old_min;

  return (value - old_min) * (new_max - new_min) / (old_max - old_min) + new_min;
}

// this function gets called when the parameters are set
void wifiParametersSet()
{
#ifdef DEBUG
  Serial.println("Wifi parameters set. Resetting ESP32.");
#endif
  ESP.restart();
}

CRGB leds[LED_NUMBER];

// territory mapping
// 1 must be subtracted from the numbering of the regions for the array
// source https://github.com/pcm-dpc/COVID-19/blob/master/dati-regioni/dpc-covid19-ita-regioni-latest.csv

constexpr uint8_t NUMERO_REGIONI = 21;
Regioni region_map[NUMERO_REGIONI] {
  {NERO, &leds[3],  nullptr},  // 0, PIEMONTE
  {NERO, &leds[4],  nullptr},  // 1, VALLE D'AOSTA
  {NERO, &leds[5],  nullptr},  // 2, LOMBARDIA
  {NERO, &leds[6],  nullptr},  // 3, TRENTO
  {NERO, &leds[8],  nullptr},  // 4, VENETO
  {NERO, &leds[7],  nullptr},  // 5, FRIULI VENEZIA GIULIA
  {NERO, &leds[1],  &leds[2]}, // 6, LIGURIA
  {NERO, &leds[9],  nullptr},  // 7, EMILIA ROMAGNA
  {NERO, &leds[0],  nullptr},  // 8, TOSCANA
  {NERO, &leds[11], nullptr},  // 9, UMBRIA
  {NERO, &leds[10], nullptr},  // 10, MARCHE
  {NERO, &leds[12], nullptr},  // 11, LAZIO
  {NERO, &leds[14], nullptr},  // 12, ABRUZZO
  {NERO, &leds[15], nullptr},  // 13, MOLISE
  {NERO, &leds[16], nullptr},  // 14, CAMPANIA
  {NERO, &leds[17], &leds[18]},// 15, PUGLIA
  {NERO, &leds[19], nullptr},  // 16, BASILICATA
  {NERO, &leds[20], nullptr},  // 17, CALABRIA
  {NERO, &leds[21], nullptr},  // 18, SICILIA
  {NERO, &leds[13], nullptr},  // 19, SARDEGNA
  {NERO, nullptr,   nullptr},  // 20, BOLZANO
};

typedef CRGB SplashScreen[NUMERO_REGIONI];
/*struct SplashScreen{
  CRGB colors[NUMERO_REGIONI];
};*/

const SplashScreen splashScreenItalia{
    VERDE, VERDE, VERDE, VERDE, VERDE, VERDE, VERDE, VERDE, VERDE,
    BIANCO, BIANCO, BIANCO, BIANCO, BIANCO,
    ROSSO, ROSSO, ROSSO, ROSSO, ROSSO, ROSSO, ROSSO,
};

void printSplashScreen(const SplashScreen &screen){
  for (int i = 0; i < NUMERO_REGIONI; i++){
    region_map[i].setColor(screen[i]);
  }
}

//---------------------------------SETUP----------------------------------------------
void setup()
{

#ifdef DEBUG
  Serial.begin(115200);
#endif

  Serial.println("-------SETUP-------");  


  // WS2812b initialization - actually they are 2813 mini
  // GRB = Color order depends on the Led model
  FastLED.addLeds<WS2812, LED_PIN, GRB>(leds, LED_NUMBER);

  // Reset LEDs
  FastLED.setBrightness(brightness_scale);
  FastLED.clear();
  FastLED.show();

  // Splashscreen Italia
  printSplashScreen(splashScreenItalia);

  FastLED.show();

  delay(3000);

  // Touch initialization
  touchSetCycles(0x1000, 0xA000);

  // PINs initialization
  pinMode(WIFI_RESET_BUTTON, INPUT_PULLUP);
  pinMode(LIGHT_SENSOR_PIN, INPUT);

#ifdef DEBUG
  Serial.println(WiFi.status());
#endif

  // setup non blocking loop
  wifiManager.setHostname(WIFI_SSID_NAME);
  wifiManager.setConfigPortalBlocking(false);
  wifiManager.setSaveConfigCallback(wifiParametersSet);

  unsigned long wifiStarted = millis();
  if (!wifiManager.autoConnect(WIFI_SSID_NAME))
  {
    while (1)
    {
      // ConfigPortal is now running
      wifiManager.process();

      // handle led animation
      EVERY_N_MILLISECONDS(0)
      {
        pacifica_loop();
        FastLED.show();
      }

      // check Reset Button
      if (digitalRead(WIFI_RESET_BUTTON) == LOW)
      {
        if (last_pressed == 0)
        {
          last_pressed = millis();
        }
        else if (millis() - last_pressed > WIFI_RESET_TIMEOUT)
        {
          // if the button is long pressed: delete WiFi credentials and reset esp
          wifiManager.resetSettings();
          ESP.restart();
        }
      }  
      else if (digitalRead(WIFI_RESET_BUTTON) == HIGH && last_pressed != 0)
      {
        // if the button is short pressed: only reset esp
        ESP.restart();
      }

      // handle WiFi timeout
      if (millis() - wifiStarted > WIFI_MAX_TIME)
      {
        // it's taking too long to connect in
        // reset everything
        #ifdef DEBUG
          Serial.println("WIFI TIMEOUT, resetting");
        #endif
        ESP.restart();
      }
    }
  }

  // now WiFi is connected
  last_connected = millis();


  // Blank screen // why? is ugly
  //FastLED.clear(); 
  //FastLED.show();


  //Serial.println("-------Fine SETUP-------");  
}

//-----------------------------------LOOP-----------------------------------------------------
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

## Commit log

2021-01-17 added grapics and proof of concept
    [frame.SLDPRT, italy-fill.dxf, proof-of-concept-v.3dm]
2021-01-17 added mockup,regions footprint reference, created board outline
    [DPCM-map.kicad_pcb]
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2021-01-17 semplificato outline regioni
    [DPCM-map.sch, frame.SLDPRT, italy-fill.dxf]
2021-01-17 added rounded edges to pcb
    [DPCM-map.kicad_pcb]
2021-01-17 moved into folders
    [DPCM-map.kicad_pcb, DPCM-map.sch, frame.SLDPRT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]
2021-01-18 wifi credentials reset if button is pressed for long enough time
    [firmware.ino]
2021-01-18 Fixed broken file
    [frame.SLDPRT]
2021-01-18 progressi col frame
    [frame.SLDPRT]
2021-01-19 Aggiunta pcb e coperchio posteriore
    [Assembly.SLDASM, frame.SLDPRT]
2021-01-20 fixed missing parenthesis triggering a compiling error
    [firmware.ino]
2021-01-20 fixed wifi credentials reset
    [firmware.ino]
2021-02-01 Fixed all things mechanical
    [2137160001.stp, Assembly.SLDASM, frame-recover.SLDPRT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]
2021-02-01 modified led structure to ws****b
    [DPCM-map.sch]
2021-02-01 updated mechanical
    [Assembly.SLDASM]
2021-02-02 v1.0 schematic
    [DPCM-map.sch]
2021-02-02 rimossi fogli gerarchici delle regioni
    [lombardia.sch, piemonte.sch, valledaosta.sch]
2021-02-02 risolti problemi di librerie
    [DPCM-map.sch]
2021-02-02 nuovi asset per bordo scheda e art interna
    [edges.dxf, keepout-zones.dxf]
2021-02-02 non so cosa sia cambiato ma qualcosa è cambiato, ma ovviamente git diff non serve a nulla con i file binari quindi committo così com'è, ciaone
    [Assembly.SLDASM]
2021-02-03 minor changes to pcb: added led footprint for comparison
    [DPCM-map.kicad_pcb, DPCM-map.sch]
2021-02-03 missing space-rino means a new commit-erino
    [firmware.ino]
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2021-02-03 add all footprints
    [DPCM-map.sch]
2021-02-03 add footprint
    [DPCM-map.sch]
2021-02-03 add LCSC ref
    [DPCM-map.kicad_pcb, DPCM-map.sch]
2021-02-03 Added ch340g in the schematic
    [DPCM-map.sch]
2021-02-03 aggiunto sistema di caricamento del codice
    [DPCM-map.sch]
2021-02-04 add graphics,edges,keepout
    [DPCM-map.kicad_pcb, edges1.dxf]
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2021-02-04 cazzo commento a fare che tanto faremo il rebase
    [DPCM-map.kicad_pcb]
2021-02-04 fixed led somehow
2021-02-04 updated schematic
    [DPCM-map.sch]
2021-02-04 removed battery
    [DPCM-map.sch]
2021-02-09 hardware cleanup, bump to next mechanical
    [edges.dxf, edges1.dxf, italy-fill.dxf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]
2021-02-09 New mechanical version: lite
    [Assembly-lite.SLDASM, Assembly.SLDASM, frame-lite.SLDPRT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]
2021-02-09 unified pins
    [DPCM-map.sch]
2021-02-09 aggiunti pulsanti fallback se non funzionasse il touch
    [DPCM-map.sch]
2021-02-10 first layout draft
    [DPCM-map.kicad_pcb, DPCM-map.sch]
2021-02-10 Aggiunti bottoni touch, rotti board edges
    [DPCM-map.kicad_pcb, DPCM-map.sch, top-buttons.dxf]
2021-02-10 did some initial routing
    [DPCM-map.kicad_pcb, DPCM-map.sch]
2021-02-11 first routing try
    [DPCM-map.kicad_pcb]
2021-02-12 routing optimization
    [DPCM-map.kicad_pcb]
2021-02-12 move oled, change tracks
    [DPCM-map.kicad_pcb]
2021-02-12 optimize routing under ESP, gnd plane, OLED position
    [DPCM-map.kicad_pcb]
2021-02-12 Fixed oled connector, fixed programming connector, added mounting points
    [DPCM-map.sch]
2021-02-12 layout properly sminchied for the happiness of giacomo
    [DPCM-map.kicad_pcb]
2021-02-13 pin swapping for layout
    [DPCM-map.sch]
2021-02-13 second fucking routing for the joy of balerio
    [DPCM-map.kicad_pcb]
2021-02-13 dio stracane se sto sbroglio non va bene Maria io esco
    [DPCM-map.kicad_pcb, DPCM-map.sch]
2021-02-13 fix touchplates, optim traces and gnd fills
    [DPCM-map.kicad_pcb, DPCM-map.sch]
2021-02-14 Consolidated BOM
    [DPCM-map.sch]
2021-02-14 added heatsink for regulator
    [DPCM-map.kicad_pcb]
2021-02-16 last routing
    [DPCM-map.kicad_pcb]
2021-02-16 Modified fields for JLCPCB BOM Assembly plugin
    [DPCM-map.sch]
2021-02-16 improved zone rules
    [DPCM-map.kicad_pcb]
2021-02-16 optimise touch plate traces and keepout
    [DPCM-map.kicad_pcb, DPCM-map.sch]
2021-02-17 flipped bme280 to get measurement from a window on the back
    [DPCM-map.kicad_pcb]
2021-02-18 added graphics, merged diverging branch
    [DPCM-map.kicad_pcb]
2021-02-19 back graphics
    [DPCM-map.kicad_pcb]
2021-02-23 optimise back graphics
    [DPCM-map.kicad_pcb]
2021-02-25 exported cpl bom and fixed graphics
    [DPCM-map.kicad_pcb]
2021-02-27 change new ws footprints
    [DPCM-map.kicad_pcb, DPCM-map.sch]
2021-02-27 realligned usb in frame
    [Assembly-lite.SLDASM, frame-lite.SLDPRT]
2021-02-27 added missing led ground
    [DPCM-map.kicad_pcb]
2021-02-28 increased spacing between touch pads as per st appnote
    [DPCM-map.kicad_pcb]
2021-02-28 route ws2813 mini and export
    [DPCM-map.kicad_pcb, DPCM-map.sch]
2021-02-28 fix last commit, add untracked files
    [DPCM-map.kicad_pcb]
2021-03-01 Added production files
    [COI_cpl.csv, DPCM-map-B_Cu.gbr, DPCM-map-B_Mask.gbr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]
2021-03-13 added reset handling during connection, color fetching from internet
    [firmware.ino]
2021-03-13 aggiornato divisorio regioni per avere linee più spesse
    [italy-fill.dxf, italy-supports.dxf]
2021-03-13 fixed wifi reset, added wifi animation
    [firmware.ino]
2021-03-14 Revert "added platformio integration"
    This reverts commit 3a084464e693f5521962d383da1e6be5d9bf1720.
    [firmware.ino, main.cpp]
2021-03-14 Revert "Revert "added platformio integration""
    This reverts commit 2585713621e31f486d2586a19b9453a0f3b17e27.
    [firmware.ino, main.cpp]
2021-03-17 change file names to colors of italy
    [DPCM-map.kicad_pcb, DPCM-map.sch]
2021-03-17 change file names to colors-of-italy
    [Colors-of-Italy.kicad_pcb, Colors-of-Italy.sch]
2021-03-18 added color correction, increased colors buffer size
    [main.cpp]
2021-03-18 ye olde manual branch merging failed, gotta do some more manual merging to fix ye olde failed manual merging
    [main.cpp]
2021-03-18 Modified frame to use M4 nuts, bigger frame size to round up in cura
    [Assembly-lite.SLDASM, frame-lite.SLDPRT]
2021-03-18 modified assets for regions dividers
    [italy-fill.dxf]
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2021-03-18 added manufacturability sources
    [CE3_frame-lite.3mf, back.dxf, frame-lite.stl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]
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2021-03-21 added brightness fix for blue
    [main.cpp]
2021-03-22 fixed blue, added brightness control
    [main.cpp]
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2021-03-23 added LED color correction
    [main.cpp]
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2021-03-24 Improved touch buttons user interface: smaller and off-center
    [Assembly-lite.SLDASM, frame-lite.SLDPRT, top-buttons.dxf]
2021-03-26 better button handling (filter fixed, added circular buffer)
    [main.cpp]
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2021-03-26 added fillet to frame buttons
    [Assembly-lite.SLDASM, frame-lite.SLDPRT]
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2021-03-26 fixed board outline
    [Colors-of-Italy.kicad_pcb]
2021-03-26 migliorato modello 3D, ora contiene front e back
    [Assembly-lite.SLDASM]
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2021-03-26 improved website, inserted images, corrected text
2021-03-27 fixed back dxf file
    [back.dxf]
2021-03-28 now esp gets reset when wifi connections fails for a long time
    [main.cpp]
2021-03-31 Propagated changes of the frame to 3MF and STL files
    [CE3_frame-lite.3mf, frame-lite.SLDPRT, frame-lite.stl]
2021-04-10 added debug prints before resets
    [main.cpp]
2021-04-10 Revert "change file names to colors-of-italy"
    This reverts commit ad0706144210016f2d85405e123c87676c1ebd15.
    [DPCM-map.kicad_pcb, DPCM-map.sch]
2021-04-10 renamed correcly files after last revert
    [Colors-of-Italy.kicad_pcb, Colors-of-Italy.sch]
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2022-09-01 Positives of italy (#42)
    * Positives of Italy
    - First working version after the abandonment by the health ministry of the concept of the colors of the regions.
    - Removed the need for an intermediate server, now the data is taken directly from the original dB
    - Added Splashscreen with Italian flag
    - Implemented Esp reset with short click on key
    - increased upload speed during developent
    - fixed build errors due to incompatibility between old WiFiManager library and new Esp core
    * Add files via upload
    - improved calculation of percentages for color selection
    - improved color selection
    * improved thresholds for color selection
    * Update main.yml
    * Modifiche post PR revie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
    [fw_defines.h, main.cpp]
2022-09-01 changes to mechanical files
    [Assembly-lite.SLDASM, Assembly.SLDASM, Coperchio.SLDPRT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]
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2022-10-08 cleaning up a little bit, reset disabled as goes crazy
    [main.cpp]
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
